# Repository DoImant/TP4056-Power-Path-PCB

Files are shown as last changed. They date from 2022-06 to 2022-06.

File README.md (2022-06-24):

# Description
A problem with the TP4056 breakout circuit is that the load must be disconnected when the battery is being charged. This is because the charging circuitry detects when the charge current falls below C/10 (constant current charge mode near the end of the charge cycle).
C is the battery capacity in mAh. When a load is connected to the battery, this changes the detected current, allowing the TP4056 to stop charging may never end!

A "bypass" consisting of an additional current path with a diode and a p-channel mosfet can help here. It is a controlled switch that disconnects the battery when an external power supply (e.g. solar cell) is connected.
TCP4056 circuit diagram

The idea is that the P-channel FET will disconnect the battery from the load when a power source is connected to the charging chip. The TP4056 still charges the battery, but with no load. The load is directly from the power source powered. With a solar cell, the battery is disconnected when sufficient solar energy is available. If it generates more electricity than the load needs, the battery is also charged.

When the power source is removed, the P-channel FET conducts, connecting the load to the battery.

With this configuration, the TP4056 can safely charge the battery when the load is connected because the battery is charged during application external power supply is disconnected from the load.

The circuit presented here implements the load distribution. The board can be glued to the back of the TP4056-breakout and be connected to the existing soldering pads.
TCP4056 R3

## Connection example
TCP4056 Connection

A detailed explanation can be found here:  [detailed explanation](https://www.best-microcontroller-projects.com/tp4056.html)

Have PCBs made: [Aisler](https://aisler.net/p/JAYYOSGH)

## Operation with solar cell
If the TP4056 breakout is operated with a solar cell, the maximum possible charging current must probably be reduced because, for example, 5V solar cells usually cannot deliver 1A charging current. A 2.5W solar cell with 5V generates a maximum charging current of 500mA. The adjustment is made on the TP4056 breakouts by swapping the resistor R3 (1.2kΩ).

|  R3 (kΩ) | I-Bat (mA) |
| ---:|---:|
| 10 | 130 |
| 5 | 250 |
| 4 | 300 |
| 3 | 400 |
| 2 | 580 |
| 1.66 | 690 |
| 1.50 | 780 |
| 1.33 | 900 |
| 1.20 | 1000 | 

A value between 2kΩ and 3kΩ would be appropriate for a solar cell such as that listed above.
TCP4056 R3

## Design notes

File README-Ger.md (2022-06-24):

# Beschreibung
Ein Problem der TP4056-Breakoutschaltung besteht darin, dass die Last getrennt werden muss, wenn der Akku geladen wird. Der Grund dafür ist, dass die Ladeschaltung erkennt, wenn der Ladestrom unter C/10 fällt (Konstantstrom-Lademodus gegen Ende des Ladezyklus). 
C ist die Akkukapazität in mAh. Wenn eine Last an dem Akku angeschlossen ist, ändert dies den erkannten Strom, sodass das TP4056 den Ladevorgang möglicherweise niemals beendet!

Ein "Beipass" aus einem zusätzlichen Strompfad mit einer Diode und einem P-Kanal-Mosfet kann hier Abhilfe schaffen. Es handelt sich um einen gesteuerterten Schalter, der den Akku trennt, wenn eine externe Stromversorgung (z.B. Solarzelle) angeschlossen wird.
TCP4056 circuit diagram

Die Idee ist, dass der P-Kanal-Fet die Batterie vom Verbraucher trennt wenn eine Stromquelle an den Ladechip angeschlossen ist. Der TP4056 lädt den Akku immer noch, aber ohne Last. Der Verbraucher wird direkt von der Stromquelle mit Strom versorgt. Bei einer Solarzelle erfolgt die Trennung vom Akku, wenn genügens Solarenergie verfügbar ist. Erzeugt sie mehr Strom als er Verbraucher benötigt, wird der Akku ebenfalls geladen.

Wenn die Stromquelle getrennt wird, wird der P-Kanal-FET leitend und verbindet die Last mit der Batterie.

Mit dieser Konfiguration kann das TP4056 die Batterie bei angeschlossener Last sicher laden, da der Akku während des Anlegens einer externer Stromversorgung von der Last getrennt ist.

Die hier vorgestellte Schaltung setzt die Lastverteilung um. Die Platine kann auf die Rückseite des TP4056 Breakouts geklebt werden und mit den vorhandnen Lötpads verbunden werden. 
TCP4056 R3

## Anschlussbeispiel
TCP4056 Connection

Eine ausführliche Erklärung ist hier zu finden: [detailierte Beschreibung](https://www.best-microcontroller-projects.com/tp4056.html)

Platine fertigen lassen: [Aisler](https://aisler.net/p/JAYYOSGH)

## Betrieb mit einer Solarzelle
Wird das TP4056-Breakout mit einer Solarzelle betrieben, so muss der max. mögl. Ladestrom reduziert werden, weil 5V Solarzellen üblicherweise nicht 1A Ladestrom liefern können. Bei einer 2,5W Solarzelle mit 5V werden maximal 500mA Ladestrom erzeugt. Die Anpassung erfolgt auf den TP4056-Breakouts, indem der Widerstand R3 (1,2kΩ) ausgetauscht wird.
 
|  R3 (kΩ) | I-Bat (mA) |
| ---:|---:|
| 10 | 130 |
| 5 | 250 |
| 4 | 300 |
| 3 | 400 |
| 2 | 580 |
| 1.66 | 690 |
| 1.50 | 780 |
| 1.33 | 900 |
| 1.20 | 1000 | 
 
Zu einer Solarzelle wie oben beispielsweise aufgeführt wurde, passt ein Wert zwischen 2kΩ und 3kΩ.
TCP4056 R3

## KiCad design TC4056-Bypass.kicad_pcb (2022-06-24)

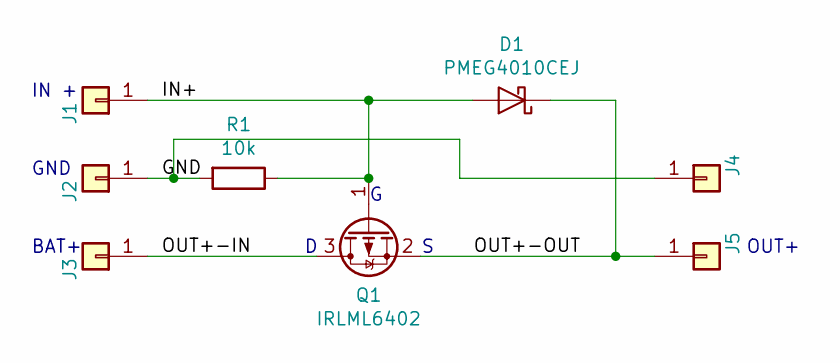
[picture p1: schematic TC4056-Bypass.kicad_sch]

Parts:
D1: PMEG4010CEJ; D_SOD-323_HandSoldering
J1, J2, J3, J4, J5: Conn_01x01; SolderWire-0.5sqmm_1x01_D0.9mm_OD2.3mm
Q1: IRLML6402; SOT-23
R1: 10k; R_1206_3216Metric_Pad1.30x1.75mm_HandSolder

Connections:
/GND: J2.1, J4.1, R1.2
/IN+: D1.2 (A), J1.1, Q1.1 (G), R1.1
/OUT+-IN: J3.1, Q1.3 (D)
/OUT+-OUT: D1.1 (K), J5.1, Q1.2 (S)

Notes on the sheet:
IN +
BAT+
OUT+
GND

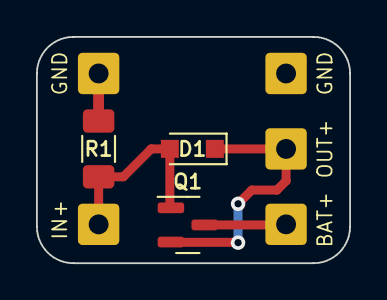
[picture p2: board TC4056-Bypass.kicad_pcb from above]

Board: 2 copper layers, 17.4 x 12.6 mm, 8 parts (0 on the bottom side), 4 nets.

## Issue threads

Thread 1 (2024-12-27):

Parts are unavailable

bilalinamdar, 2024-12-27:
Nice project ! The parts are unavailable. Can you update ?
Have PCBs made: [Aisler](https://aisler.net/p/JAYYOSGH)

DoImant, 2024-12-27:
What's about this?

[](https://www.reichelt.de/de/de/shop/produkt/mosfet_p-ch_-20v_-3_7a_0_065r_sot-23-108743)

[](https://www.mouser.de/ProductDetail/Infineon-Technologies/IRLML6402TRPBF?qs=9%252BKlkBgLFf0HuZuONx2Ewg%3D%3D)

[](https://www.reichelt.de/de/de/shop/produkt/schottkydiode_40_v_1_a_sod-323-219552)

[](https://www.mouser.de/ProductDetail/Nexperia/PMEG4010CEJ115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)

bilalinamdar, 2024-12-30:
Sorry it is not available at my location
can you please see below .

SS14 - The SS14 Diode is a SMD version of 1N5819 Diode - SS14 Diode – Schottky – SMA (DO-214AC)
https://www.ktron.in/product/ss14-diode/
DATASHEET - https://www.ktron.in/wp-content/uploads/2020/02/KSTD0410-SS14-Diode-Datasheet.pdf

AO3401A MOSFET – 30V 4A – P-Channel Mosfet
https://www.ktron.in/product/ao3401a-mosfet-30v-p-channel/
DATASHEET - https://www.ktron.in/wp-content/uploads/2023/05/AO3401A.pdf

Will this work ?

DoImant, 2025-01-01:
The components should also work. However, the diode should have a SOD323 footprint.
